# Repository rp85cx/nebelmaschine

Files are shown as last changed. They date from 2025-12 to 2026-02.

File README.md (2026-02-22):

# V2 der geupgradeden Nebelmaschine
### dual core - warum nicht?

>[!NOTE]
> Disclaimer: der Code wurde basically komplett ohne KI geschrieben, wenn nur kleines problem solving deswegen bitte nicht wundern wenn der unstrukturiert oder unklar wie sonst noch was ist :)

### How to use:

Encoder unter dem Display drehen, klick für Action bzw in Menu gehen, langes Drücken um aus jeder Page zurück ins Menu zu kommen

Einzelne Pages sind wahrscheinlich selbsterklärend, Einstellungen werden auch nach Aus-Anmachen gespeichert. DMX kann auf der Page "DMX Adresse" und "DMX Debug" gedebuggt werden, bei erstem welchen Wert er empfängt, bei letzterem wie viele DMX Packets pro Sekunde ankommen.

Falls jemand je das Ding aufmachen und Troubleshooten muss, ist hier das Layout wie die Stecker in die Platine kommen

> [!WARNING]
> **NIEMALS** die Nebelmaschine aufmachen während sie an ist, und falls man sie offen Testen muss **AUF KEINEN FALL** irgendwas im inneren anfassen. Dabei liegen **230V Netzspannung** an, die zum schlimmsten führen können!

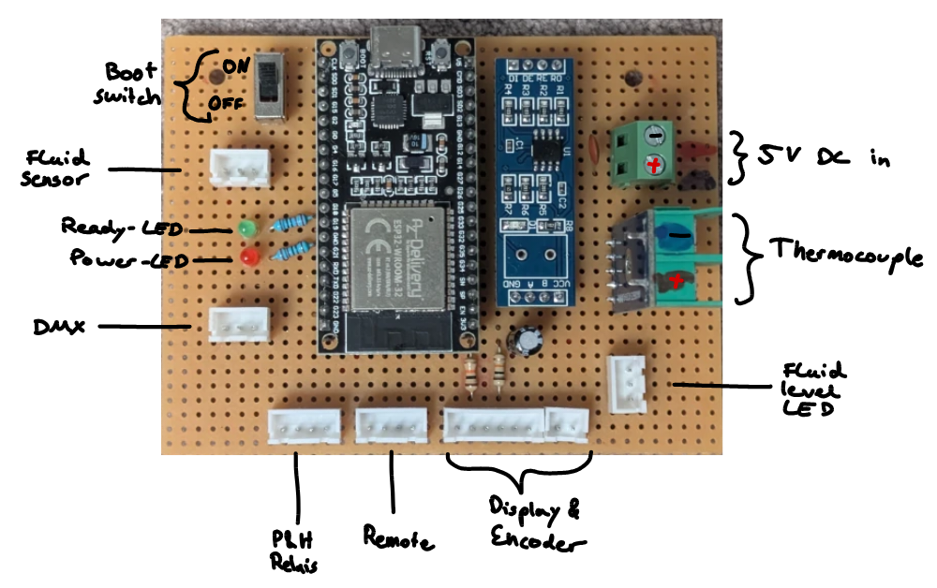
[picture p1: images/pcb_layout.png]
Layout of the PCB with notes for where to plug in what


### Hardware:
- ESP32 Wroom
- Max485 für DMX 
- Max6675 für Temperatur via Thermocouple
- Rotary Encoder für main Eingabe an einem
- Noname 128x64 OLED Display
- paar LEDs, Wiederstände uä

### Credits:
- [Upir](https://www.youtube.com/@upir_upir)
- [Randomnerdtutorials](https://randomnerdtutorials.com)

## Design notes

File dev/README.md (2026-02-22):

"old uno" - alte Files, eigentlich Unnötig aber falls man was nachschauen muss oder so übersichtlichtkeitshalber hier

"nebelmaschine-esp32" - nicht zu verwechseln mit der im Main branch, hier wurde mit WIFI experimentiert doch gibt es dabei Bugs mit der Temperaturauslesung weshalb die Idee Zeitlich verworfen wurde

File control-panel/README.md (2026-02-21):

# stls für die rückseite
control panel hält display und encoder
dip cover ist damit kein loch ist wo früher die dip switch zum dmx adress selecten war

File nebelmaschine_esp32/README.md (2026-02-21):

# Code für ESP32
man braucht alle 4 Dateien, dabei ist die wie der Ordner genannte die main

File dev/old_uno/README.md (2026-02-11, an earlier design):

# alte doku der nebelmaschine mit arduino uno

Dokumentation für die reparierte, neu "verdrahtete" Nebelmaschine Stairville M-Fog 1500

Source Code "fogm_buttoncntrl.ino" für Arduino Uno

**Arduino Pinouts zu:**
- 9: ready-led
- 3: status-led 2
- 5: status-led 1
- 10: Max6675 CS
- 12: Max6675 SO
- 13: Max6675 SCK
- 8: Heat Relay
- 7: Pump Relay
- A1: Control Button
- 4: TM1637 CLK (dev)
- 2: TM1637 DIO (dev)

**Status LED (1: Orange/Gelb, 2: Grün):**
- Power: 1 dunkel
- Heat: 1 hell
- Ready: 2 leuchtet
- Output: 2 blinkt

- Eingebautes Control board noch unfunktional, außerdem Pumpe nur an/aus 
- Externer Stecker pinouts (GX16, 4-Pin):
	- 1: 5 (sled 1, 5v!) kabel: gelb
	- 2: 3 (sled 2, 5v!) kabel: grün
	- 3: a1 (trigger to gnd) kabel: braun/orange
	- 4: gnd kabel: weiß
- Sicherung: F8AL250V 5 * 20mm
- Temps:
	- heizen bis 230°
	- ab 240° keine möglichkeit mehr drüber zu gehen
	- pumpe geht ab 210°
- 2x 10a relais für Pumpe/Heater

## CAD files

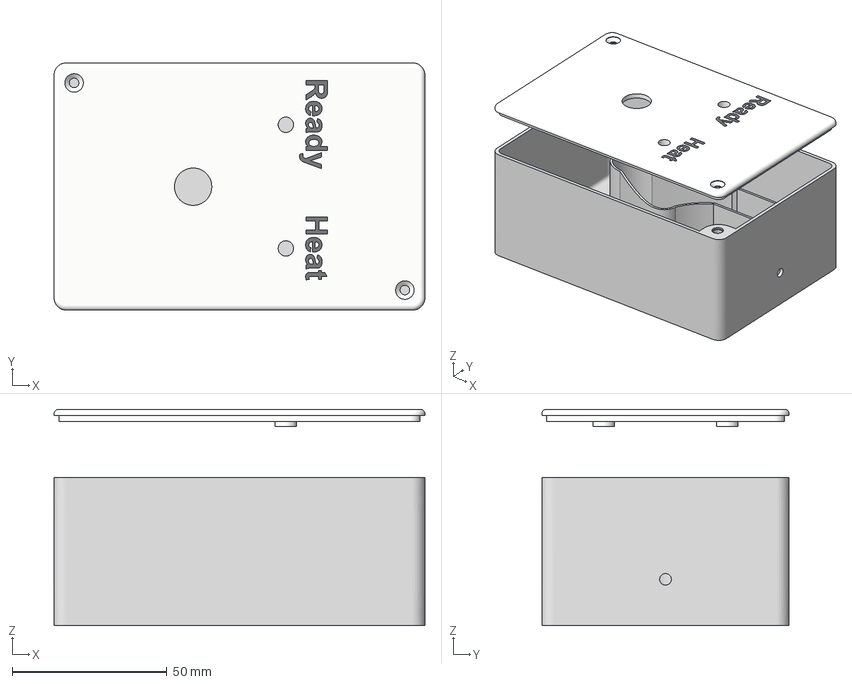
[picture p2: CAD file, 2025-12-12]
control-box/fogm_controlbox2.3mf
120.0 x 80.0 x 70.0 mm
Körper10
Körper11
Körper3
Körper4
Körper5
Körper6
Körper7
Körper8
Körper9
deckel

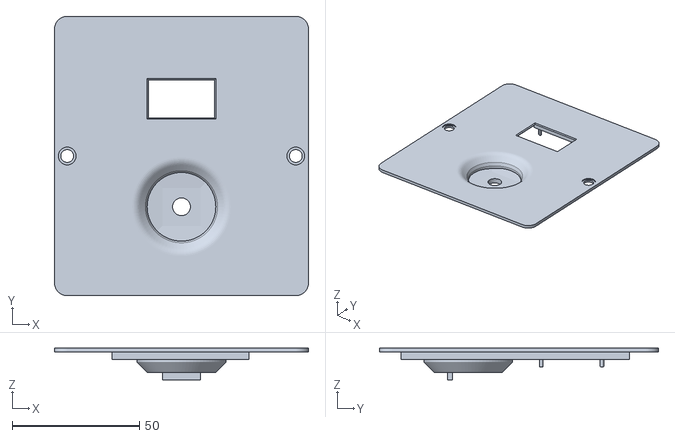
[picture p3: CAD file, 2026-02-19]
control-panel/nebelmaschine_panelv2.stl
100.0 x 110.0 x 12.5

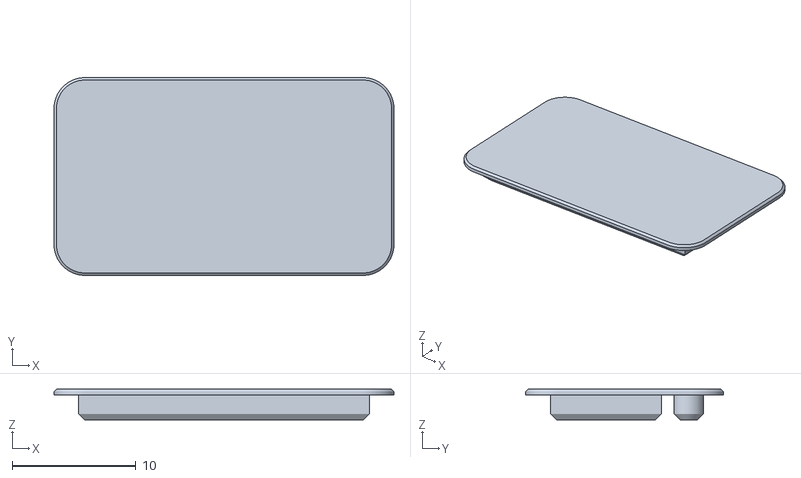
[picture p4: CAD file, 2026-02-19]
control-panel/nebelmaschine_dip-cover.stl
27.5 x 16.0 x 2.50

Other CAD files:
control-box/fogm_controlbox2.f3d

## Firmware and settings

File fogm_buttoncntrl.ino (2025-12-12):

#include <TM1637Display.h>
#include <max6675.h>

#define CLK 4
#define DIO 2
TM1637Display display(CLK, DIO);

#define thermoDO 12   // SO
#define thermoCS 10   // CS
#define thermoCLK 13  // SCK
MAX6675 thermocouple(thermoCLK, thermoCS, thermoDO);


const int heaterPin = 8;   // heating relay (inverted)
const int pumpPin = 7;     // pump relay (inverted)
const int ledReady = 9;    // ready LED
const int buttonPin = A1;  // trigger button (on=low)
const int sled1 = 5;       // smart LED 1(pwm)
const int sled2 = 3;       // smart LED 2(pwm)


const float TEMP_READY = 210.0;
const float TEMP_HEAT_STOP = 230.0;
const float TEMP_CUTOFF = 240.0;


const unsigned long TEMP_INTERVAL = 250;
unsigned long lastTempRead = 0;
float tempC = 0;


const unsigned long RELAY_MIN_INTERVAL = 3000;
unsigned long lastHeaterSwitch = 0;
unsigned long lastPumpSwitch = 0;


const int SLED1_DIM = 15;      // dim brightness when idle
const int SLED1_BRIGHT = 255;  // bright when heating


const unsigned long PUMP_MIN_ON = 100;
unsigned long pumpTurnOnTime = 0;


const unsigned long BLINK_INTERVAL = 250;
unsigned long lastBlinkTime = 0;
bool blinkState = false;


bool heaterState = true;  //inverted
bool pumpState = true;    //inverted




void setup() {
  Serial.begin(9600);

  pinMode(heaterPin, OUTPUT);
  pinMode(pumpPin, OUTPUT);
  pinMode(ledReady, OUTPUT);
  pinMode(sled1, OUTPUT);
  pinMode(sled2, OUTPUT);
  pinMode(buttonPin, INPUT_PULLUP);

  digitalWrite(heaterPin, HIGH);
  digitalWrite(pumpPin, HIGH);

  analogWrite(sled1, SLED1_DIM);
  analogWrite(sled2, LOW);

  display.setBrightness(7);
  display.clear();

  delay(500);
}




void loop() {

  if (millis() - lastTempRead >= TEMP_INTERVAL) {
    lastTempRead = millis();
    tempC = thermocouple.readCelsius();

    Serial.print("Temp: ");
    Serial.println(tempC);

    display.showNumberDec((int)tempC, false);
  }

  bool isReady = (tempC > TEMP_READY);
  digitalWrite(ledReady, isReady ? HIGH : LOW);

  bool buttonPressed = !digitalRead(buttonPin);  //  inverted

  bool desiredPumpState = true;  // default OFF
  bool isSmoking = false;

  if (buttonPressed && isReady) {
    desiredPumpState = false;  // ON
    isSmoking = true;
  }

  setPump(desiredPumpState);


  bool desiredHeaterState = true;  // OFF
  bool heaterActive = false;

  if (tempC >= TEMP_CUTOFF) {
    desiredHeaterState = true;
  } else {
    if (buttonPressed && isReady) {
      desiredHeaterState = false;
      heaterActive = true;
    } else if (tempC < TEMP_HEAT_STOP) {
      desiredHeaterState = false;
      heaterActive = true;
    } else {
      desiredHeaterState = true;
    }
  }

  setHeater(desiredHeaterState);



  if (heaterActive) {
    analogWrite(sled1, SLED1_BRIGHT);
  } else {
    analogWrite(sled1, SLED1_DIM);
  }


  if (millis() - lastBlinkTime >= BLINK_INTERVAL) {
    lastBlinkTime = millis();
    blinkState = !blinkState;
  }

  if (isSmoking) {

    analogWrite(sled2, blinkState ? 255 : 0);
  } else if (isReady) {

    analogWrite(sled2, 255);
  } else {

    analogWrite(sled2, 0);
  }
}




void setHeater(bool newState) {
  if (newState != heaterState && millis() - lastHeaterSwitch >= RELAY_MIN_INTERVAL) {

    heaterState = newState;
    digitalWrite(heaterPin, heaterState);
    lastHeaterSwitch = millis();
  }
}




void setPump(bool newState) {
  unsigned long now = millis();

  if (newState == false) {
    if (pumpState == true) {
      pumpState = false;
      digitalWrite(pumpPin, LOW);
      pumpTurnOnTime = now;
      lastPumpSwitch = now;
    }
    return;
  }

  if (pumpState == false) {

    if (now - pumpTurnOnTime < PUMP_MIN_ON)
      return;
  }

  if (now - lastPumpSwitch >= PUMP_MIN_ON) {
    pumpState = true;
    digitalWrite(pumpPin, HIGH);
    lastPumpSwitch = now;
  }
}

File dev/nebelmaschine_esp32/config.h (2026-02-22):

hw_timer_t *timer = NULL;
volatile bool readTempNow = false;

//--------config-------------
char menu_items[10][15] = {
  { "Manuell" },
  { "Wifi" },
  { "Timer" },
  { "Heat an/aus" },
  { "DMX Adresse" },
  { "DMX Mode" },
  { "DMX Debug" },
  { "Home" },
  { "Help" }
};

const char* AP_SSID = "Nebelmaschine";  //wifi ap name und passwort für webpage control - am besten max. 15 chars
const char* AP_PWD = "einPasswort";  //ich weiß dass das in github steht aber irgendwo solls auch zu finden sein falls jmd braucht :)

const int inactivityTime = 120;     //in s; -120-       invert time = inactivity time * 5
const int tempCheckInterval = 500;  //in ms >200; -500-
const int dmxUpdateInterval = 100;  //in ms; -100-
const int maxFoggingTime = 90;      //in s; -60-
const int pingTimeout = 500;        //in ms >250; -500-    webpage timeout bis als false gesehen wird 

const int led_dunkelPwm = 8;       //helligkeit von dunkler status led, 0-255; -8-

const int foggingTimeOnDisplayPress = 500;  //wie lange (ms) foggen soll wenn in manuell page geklickt wurde -500-

const bool debugMode = true;            //serial feedback active oder nicht

//-------pin declarations-------- 
const int relay_heatPin = 19;
const int relay_pumpPin = 18;
const int led_ready = 32;
const int led_pwrHeat = 12;
const int led_rdyOut = 13;
const int triggerButton = 14;
const int led_fluidRed = 5;
const int led_fluidBlue = 4;
const int encoderA = 0;
const int encoderB = 2;
const int encoderButtonPin = 15;
const int thermocoupleDO = 26;
const int thermocoupleCS = 25;
const int thermocoupleCLK = 33;
const int fluidSensorPin = 23;
const int dmxRX = 16;   //RO
const int dmxTX = 17;   //DI
const int dmxRTS = 27;  //connect to RE und DE - enable to both

const float temp_ready = 200.0;    //prod: -200-
const float temp_heatMax = 225.0;  //prod: -225-
const float temp_pumpMax = 235.0;  //prod: -235-


//----------program variables and class calls-----------------
U8G2_SSD1306_128X64_NONAME_F_HW_I2C u8g2(U8G2_R0);
RotaryEncoder encoder(encoderA, encoderB, RotaryEncoder::LatchMode::FOUR3);
OneButton encoderButton(encoderButtonPin, true, false);
Preferences preferences;
MAX6675 thermocouple(thermocoupleCLK, thermocoupleCS, thermocoupleDO);
WebServer server(80);
TaskHandle_t core0;
TaskHandle_t core1;

volatile int menu_selected = 7;
volatile int current_screen = 1;
int lastMenu_selected;
int lastCurrent_screen;
int edit_selected = 0;
bool editMode = false;
volatile bool action = true;
unsigned long lastAction = millis();
unsigned long lastInvert = millis();
unsigned long lastTempUpdate;
unsigned long lastTrigger;
unsigned long lastLedUpdate;
unsigned long lastDmxPPSUpdate;
unsigned long lastDmxUpdate;
unsigned long lastTimerUpdate;
unsigned long lastTriggerButtonCheck;
unsigned long lastHeatStateChange;
unsigned long foggingTime;
unsigned long lastPing;
int lastLedControlState=6;;
int ledControlState;
bool buttonPressed = false;
char stringBuffer[4];
const int menu_itemsLength = (sizeof(menu_items) / sizeof(menu_items[0])) - 1;
byte dmxData[513];
int dmxPPS = 0;
int calcDmxPPS = 0;
bool timerState = false;
int item_sel_next = 0;
int item_sel_previous = 0;
volatile bool dmxIsConnected = false;
volatile int dmxValue = 0;
volatile bool ledState=false;
volatile bool ready = false;
volatile bool relay_heat = false;
volatile bool relay_pump = false;
volatile bool foggingActive = false;
volatile bool foggingActiveDisplay = false;
volatile bool foggingActiveButton = false;
volatile bool foggingActiveDMX = false;
volatile bool foggingActiveTimer = false;
volatile bool foggingActiveWeb = false;
volatile bool foggingAllowed = true;
bool displayInverted=false;
bool lastFoggingState;
//bool timerActive = false;   // -> preferences
//int timerOff = 60;   // -> preferences
//int timerOn = 30;   // -> preferences
//bool heatActive = true;   // -> preferences
volatile int temperature = 0;  //dev: = 200 prod: = 0
//int dmxAdress = 1;   // -> preferences
//int dmxMode = 1;  // -> preferences
volatile bool dmxActive = true;  // -> preferences für core0, local var für core1

/*
default core setup:
xTaskCreatePinnedToCore(  
    task1code, // Task function. 
    "task1",   // name of task. 
    10000,     // Stack size of task 
    NULL,      // parameter of the task 
    1,         // priority of the task 
    &task1,    // Task handle to keep track of created task 
    0);        // pin task to core 0 
  delay(500);
  ps.: du brauchst diesen absoluten hässlichen code auch nicht lesen gell
*/

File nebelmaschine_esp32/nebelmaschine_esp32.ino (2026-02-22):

/*
v2.6
Board library ESP32 by Espressif System <= 2.0.17 
ich hoffe du verstehst denglisch

"kleines" Projekt um eine Nebelmaschine fast smart zu machen
*/
#include <U8g2lib.h>
#include <RotaryEncoder.h>
#include <OneButton.h>
#include <Preferences.h>
#include <max6675.h>
#include <esp_dmx.h>

#include "config.h"
#include "functions.h"

void setup() {
  if (debugMode) Serial.begin(115200);

  initPins();
  setInitalState();
  initLibs();

  xTaskCreatePinnedToCore(code0, "core0", 10000, NULL, 2, NULL, 0);
  delay(200);

  xTaskCreatePinnedToCore(code1, "core1", 10000, NULL, 1, NULL, 1);
  delay(200);

  if (debugMode) Serial.println("initialised");
}


void code0(void* pvParameters) {
  while (true) {
    encoder.tick();        //update encoder
    encoderButton.tick();  //update encoder button

    encoderMenuScroll();

    checkTemp(true);  //temperatur check im interval  -> true = action call nach temp read falls menu damit

    checkInactivity();

    systemControl();

    timerControl();

    dmxInPrefs();

    if (action) {
      action = false;

      calcShownItems();
      drawScreen();
    }

    pageFunctions();
  }
}


void code1(void* pvParameters) {
  while (true) {
    ledControl();

    dmxControl(true);
  }
}


void loop() {}

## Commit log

2026-02-12 bugfixes and feature update
    [config.h, functions.h, nebelmaschine_esp32.ino]
2026-02-16 double prefs access fix
    [config.h, functions.h, nebelmaschine_esp32.ino]
2026-02-17 fixed button input
2026-02-21 minor bugfix and feature update
    [config.h, functions.h, nebelmaschine_esp32.ino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]
